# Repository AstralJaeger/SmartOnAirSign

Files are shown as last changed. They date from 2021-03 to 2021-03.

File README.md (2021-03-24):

# Smart OnAir Sign
<br />This work is licensed under a <a rel="license" href="http://creativecommons.org/licenses/by-nc-sa/4.0/">Creative Commons Attribution-NonCommercial-ShareAlike 4.0 International License</a>.

Also available on Thingiverse: https://www.thingiverse.com/thing:4804813

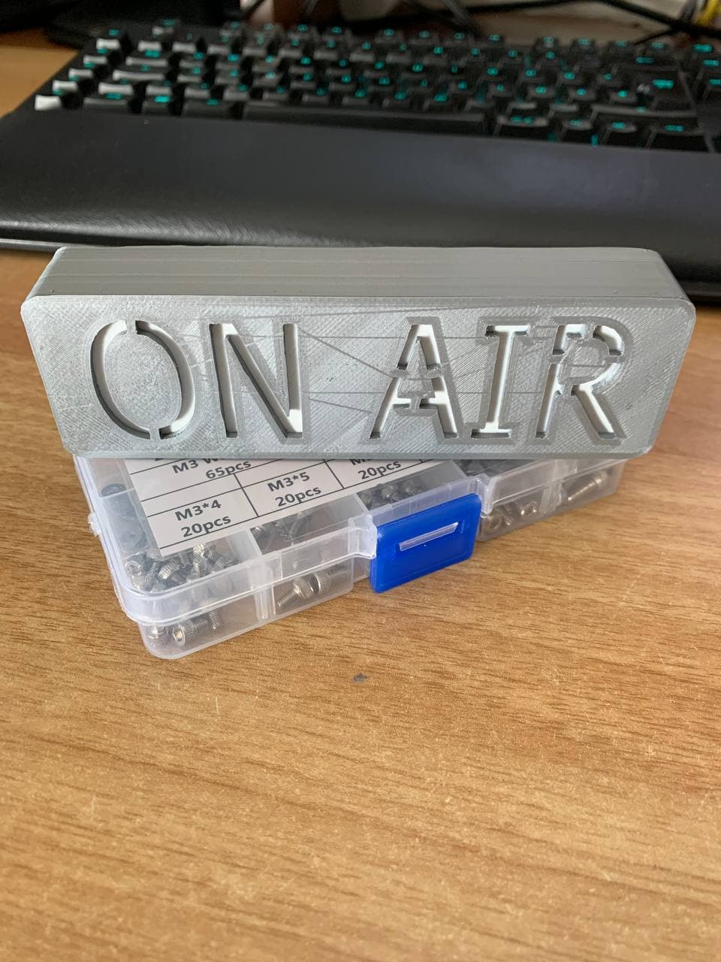
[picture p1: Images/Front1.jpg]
Front Picture

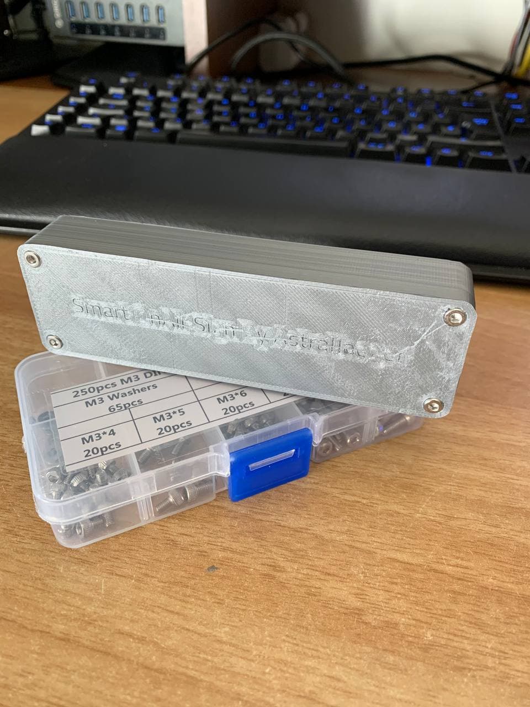
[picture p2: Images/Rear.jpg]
Rear Picture


Do you know this issue, you are in a remote meeting and suddenly your roommate/significant other walks in and wants to talk to you?
I certainly do, that's why I designed this WiFi enabled on-air sign because I couldn't find one I liked.

The device operates rather simply: 
A web server runs on a Wemos D1 mini which hosts an mDNS enabled web server with can be easily reached with the URL http://onairsign.local/. 
In order to manipulate the color the device displays the URL http://onairsign.local/color can be used with the following parameters:

| Parameter | Description | Example |
|---|---|---|
| **r** | This parameter changes the red part of the displayed color. Values range from 0 to 255, whole numbers only. | http://onairsign.local/color?r=128 |
| **g** | This parameter changes the green part of the displayed color. Values range from 0 to 255, whole numbers only. | http://onairsign.local/color?g=128 |
| **b** | This parameter changes the blue part of the displayed color. Values range from 0 to 255, whole numbers only. | http://onairsign.local/color?b=128 |
| **lum** | This parameter changes the brightness of the led's. Values range from 0 to 255, whole numbers only. | http://onairsign.local/color?lum=128 |
| **s** | This is the status parameter. Values may be 0, 1 or 2. 0 displays a rainbow wave, 1 displays the set color, 2 turns the display off.  | http://onairsign.local/color?s=1 |

## Examples
- This sets the color to red at full brightness: 
http://onairsign.local/color?r=255&g=0&b=0&lum=255&s=1
- This disables the display: http://onairsign.local/color?s=2
- This shows a rainbow wave: http://onairsign.local/color?s=0

## Required tools
- 3D printer (obviously)
- Soldering iron
- Solder 
- Allen key

## BOM
- *1 x* **[LOLIN (WEMOS) D1 Mini](https://it.aliexpress.com/item/32529101036.html?spm=a2g0s.9042311.0.0.653f4c4dwwleCD)**
- *1 x* **[WS2812B 5V LED strip](https://it.aliexpress.com/item/2036819167.html?spm=a2g0s.9042311.0.0.653f4c4dAy9aew)**
- *4-6 x* **[M3x8 or M3x12 Screws](https://it.aliexpress.com/item/32846918173.html?spm=a2g0s.9042311.0.0.653f4c4dAy9aew)**
- *1 x* **3D printed top shell**
- *1 x* **3D printed bottom shell**
- *1 x* **3D printed light diffuser or sheet of paper** (optional)

## Printing instructions
### Top shell
Avoid using a brim, turn the flat side with the text to the bottom. Do NOT drill out the screw holes, the screws should tap into this side.

### Diffuser
Print using 0.16 mm layer height, this way it will end up being 2 layers, print it in white filament. If you don't have white filament at hand, just cut out a sheet of paper or omit the whole thing, it just prevents you from seeing the electronics.

### Bottom shell
No brim should be necessary, if used, you'll have to clear out the screw holes. May need to drill out the screw holes, these are just through-holes on this side.

## Assembly
### Step 1
Glue the diffuser in place, I used some Bostik superglue, but any glue that sticks to your material of choice will do. 
The diffuser may need some trimming in the corner.

### Step 2
Cut the LED strip into 3 or 4 pieces, connect them with some short wires (1 - 1.5cm or about 1/2"). 
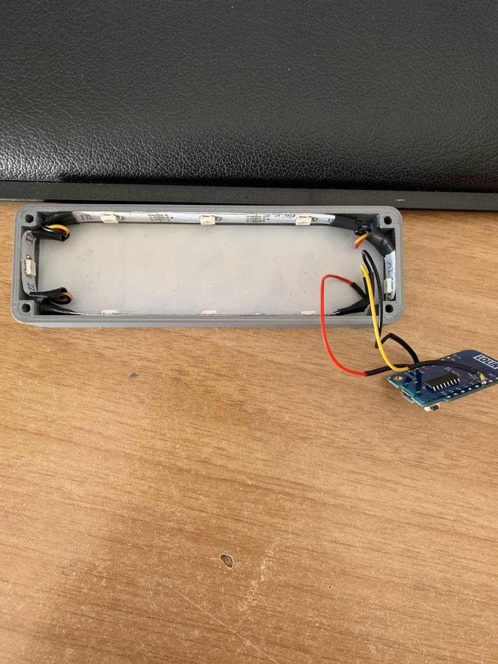
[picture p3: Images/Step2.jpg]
Step 2 - image


### Step 3
Solder a slightly longer piece of wire to the beginning of your LED strip and to the bottom (The top is the side with the USB port) of your Wemos, 5V goes to 5V, GND to GND and DIn to GPIO16 or D0 of the board.
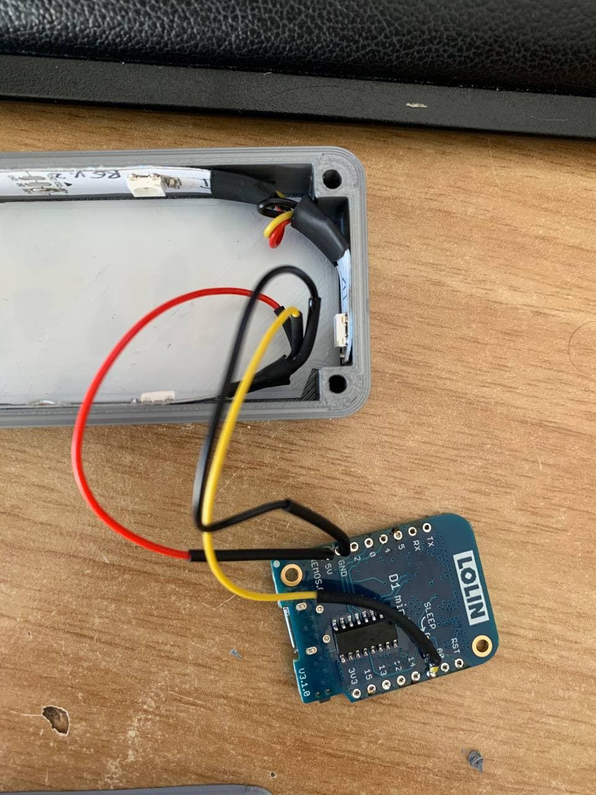
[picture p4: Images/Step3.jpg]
Step 3 - image

Step 3 - Wemos pinout

### Step 4
Push the Wemos into its slot on the bottom shell, usb port should point down, it should be a tight fit and stay in-place without any glue. 
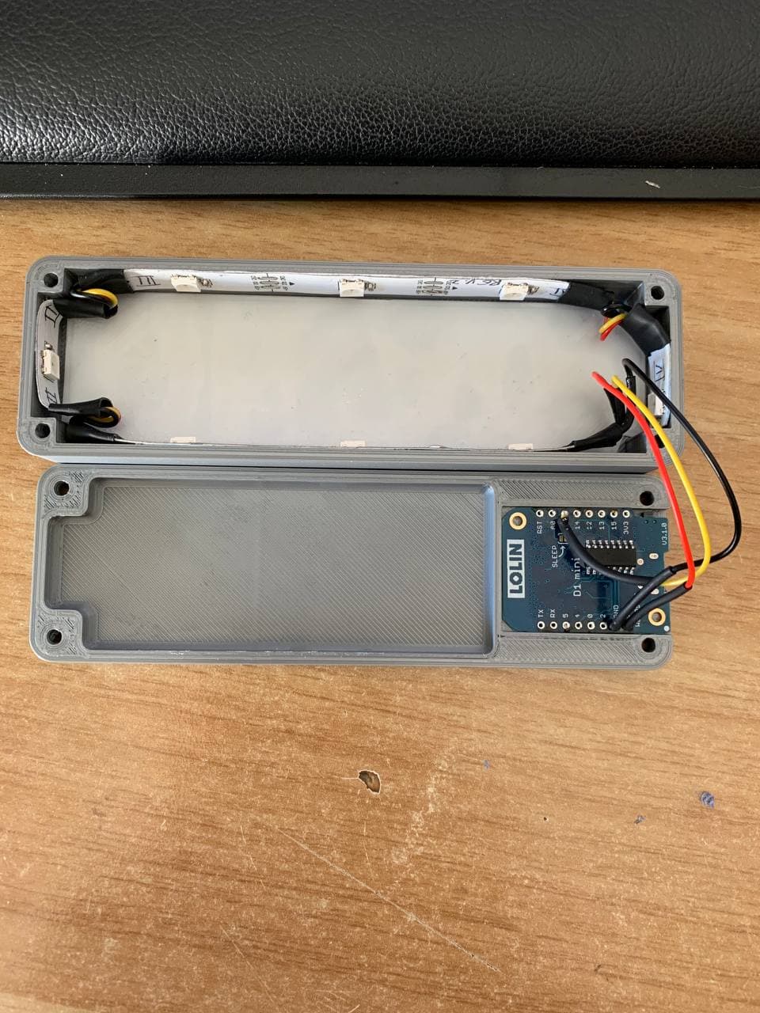
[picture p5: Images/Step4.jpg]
Step 4 - image


### Step 5
Before closing your Project, make sure to upload the code available [here](/blob/master/Code/ESP/ESP8622_Code) using the Arduino IDE or PlatformIO or VisualMicro. **Make sure to enter your WiFi ssid and password in the code!** 
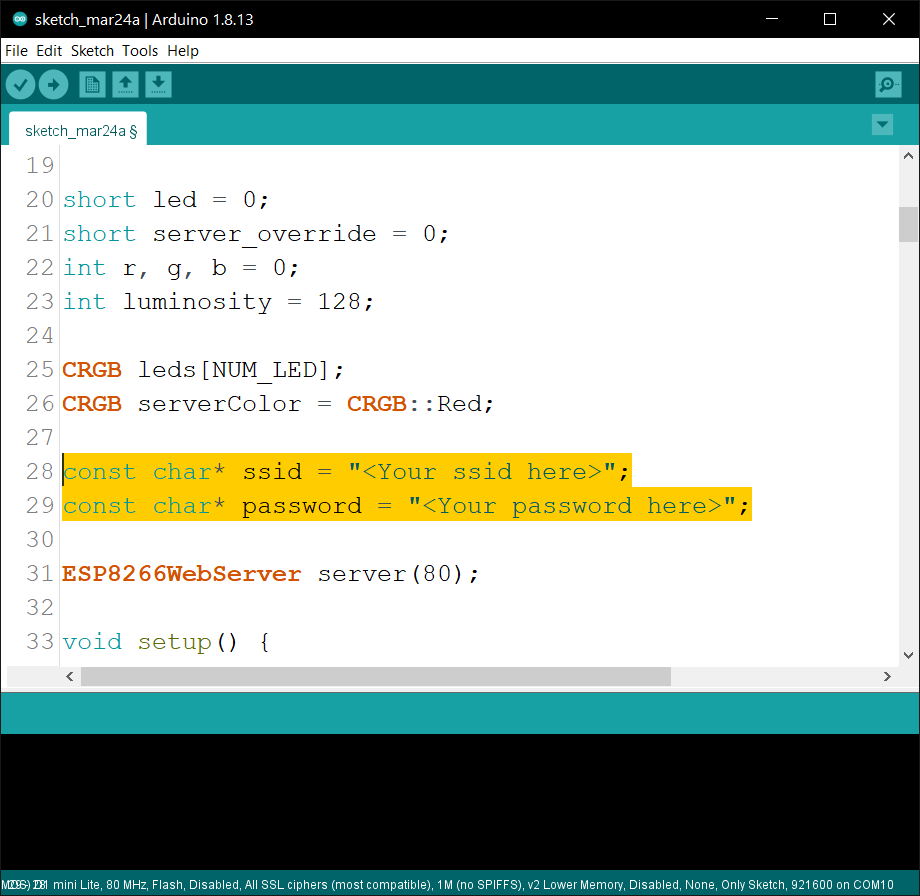
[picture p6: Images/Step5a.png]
Step 5 - Boardmanager


In order to get the correct device to upload your code you may need to add this ``https://arduino.esp8266.com/stable/package_esp8266com_index.json`` to your Preferences -> Additional Boardmanager URL's.
Then download the necessary files using the board manager.
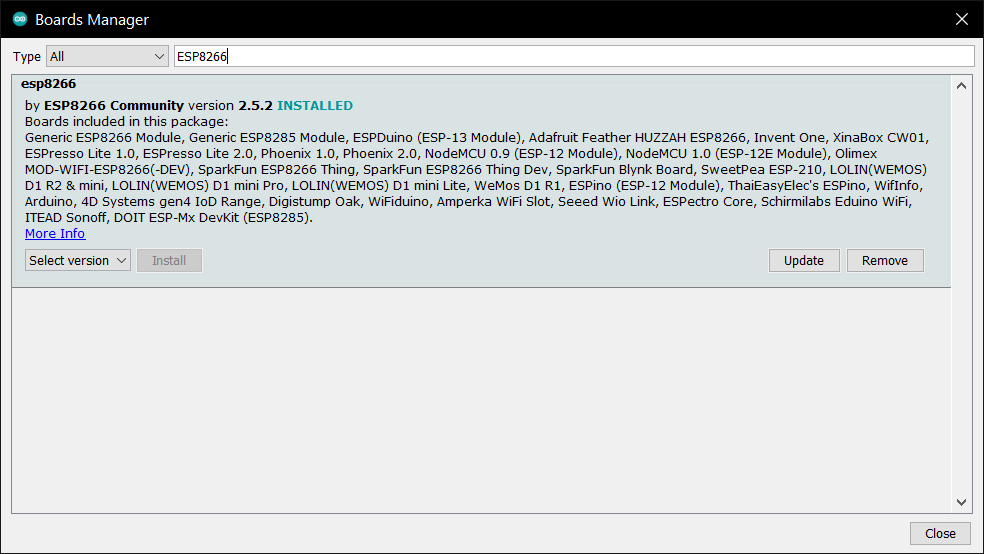
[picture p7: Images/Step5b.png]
Step 5 - Boardmanager


After uploading, open the Serial Monitor and wait for the device to start up. There is a 2 second startup sanity delay as recommended by the FastLED library.
Wait until your serial monitor output looks similar to this: 
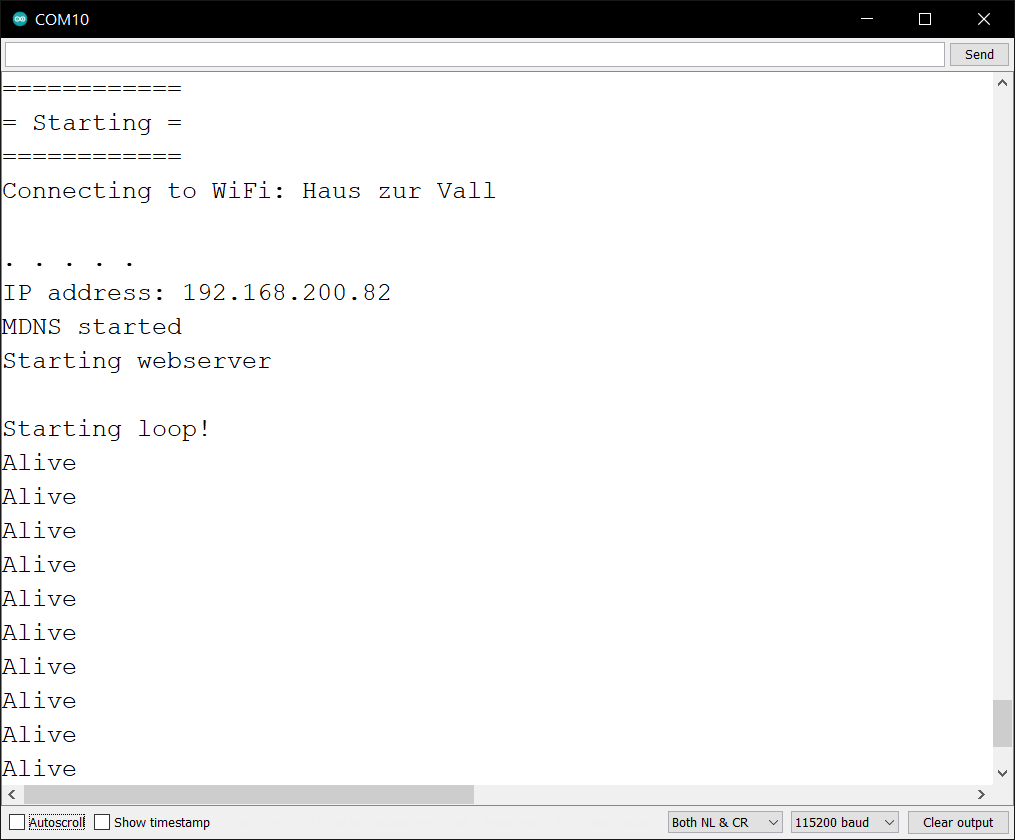
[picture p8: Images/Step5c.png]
Step 5 - Serial monitor


### Step 6
Now when your LED's light up, you can close the case and enjoy your new On Air sign!
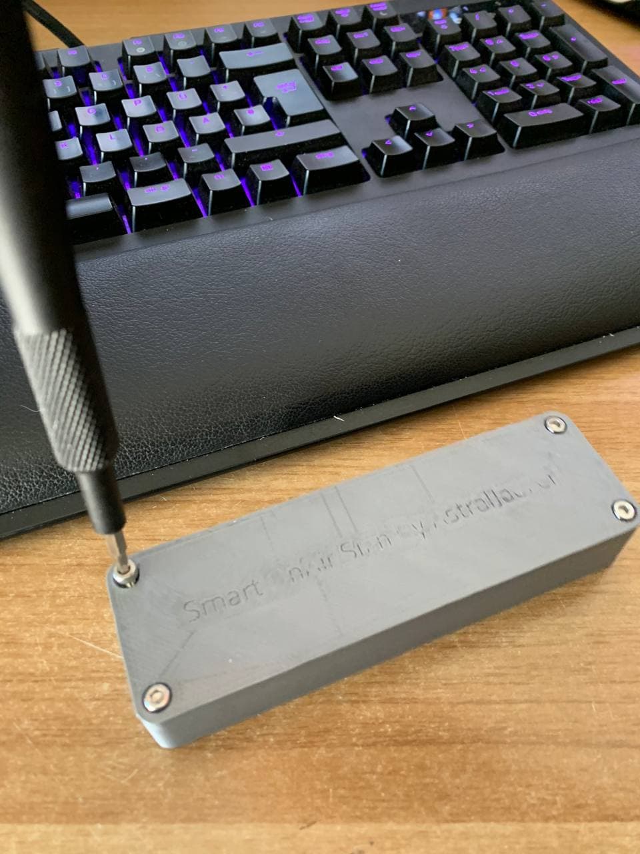
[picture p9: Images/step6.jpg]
Step 6 - Last screw


## BOM Reference Pictures
- LOLIN D1 Mini
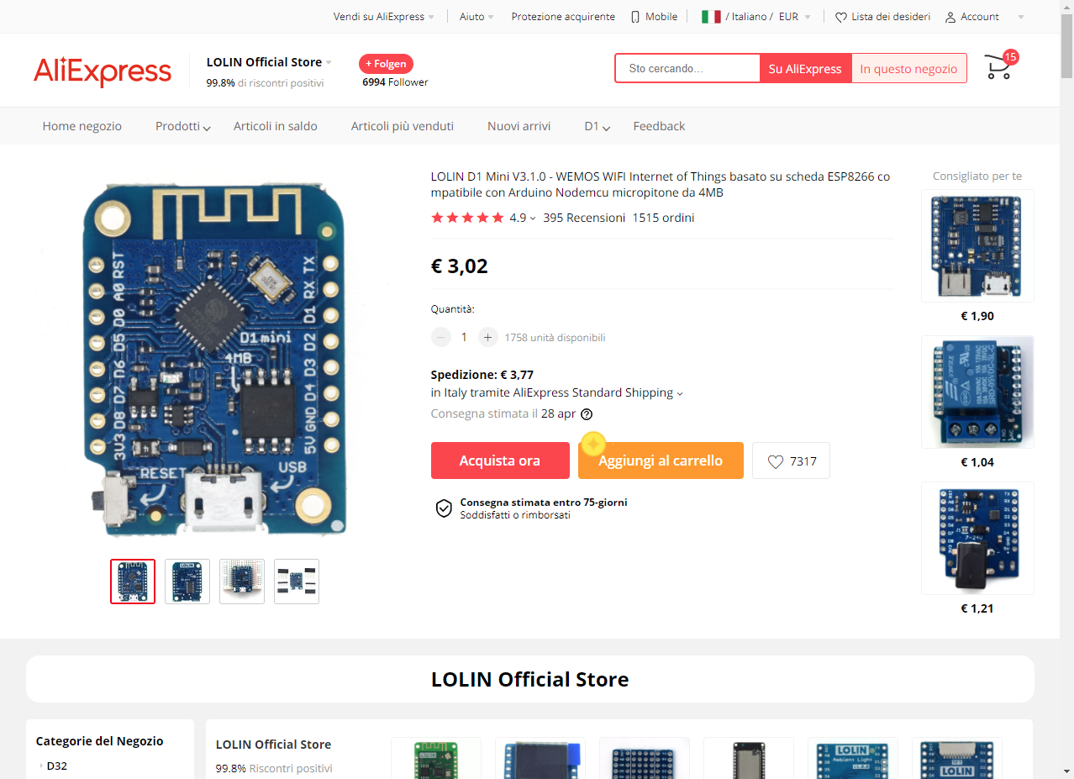
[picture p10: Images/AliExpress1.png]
Wemos D1 mini

- ARGB LED Strip
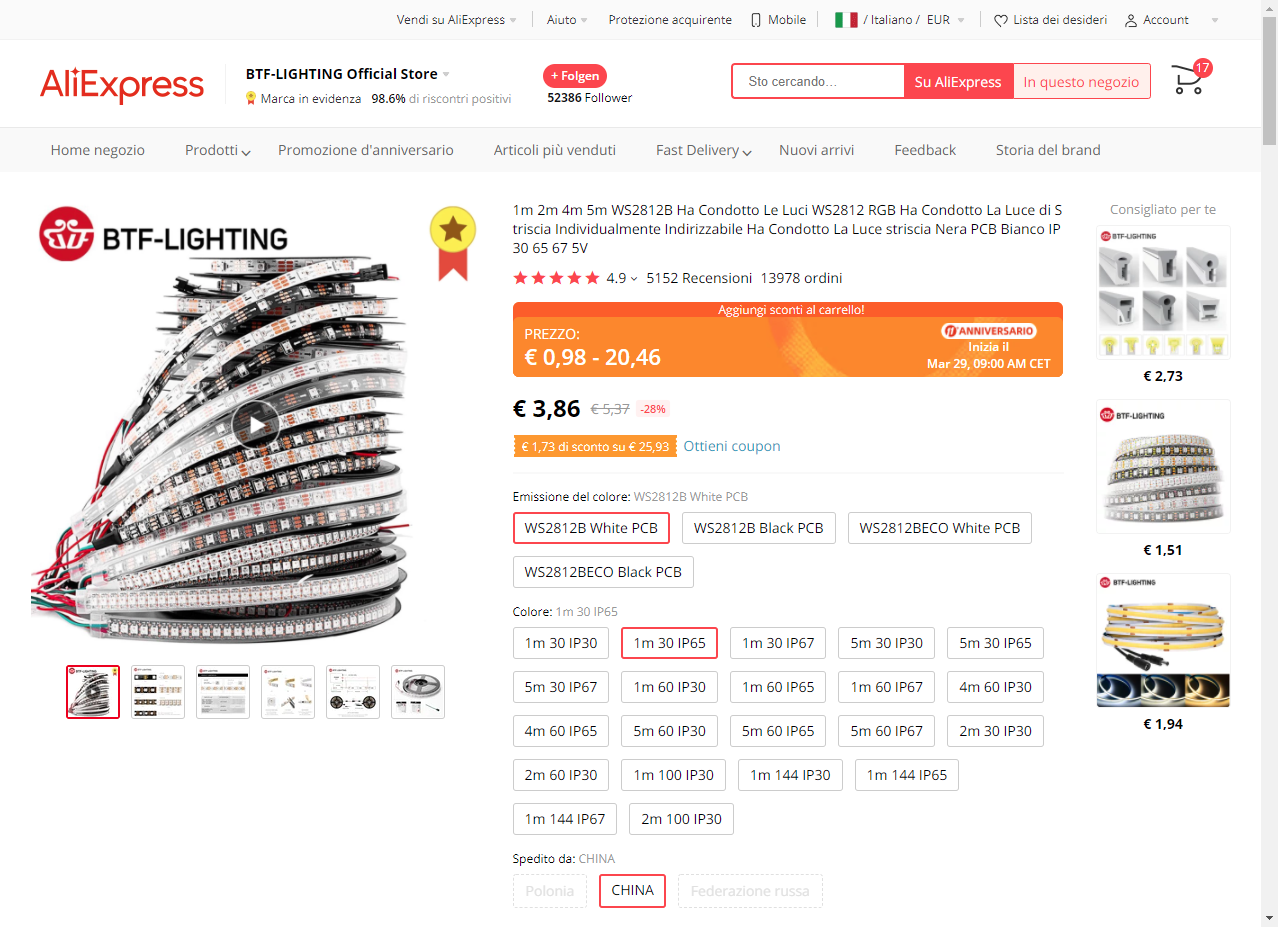
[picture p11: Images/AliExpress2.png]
ARGB LED strip

- M3 Screws
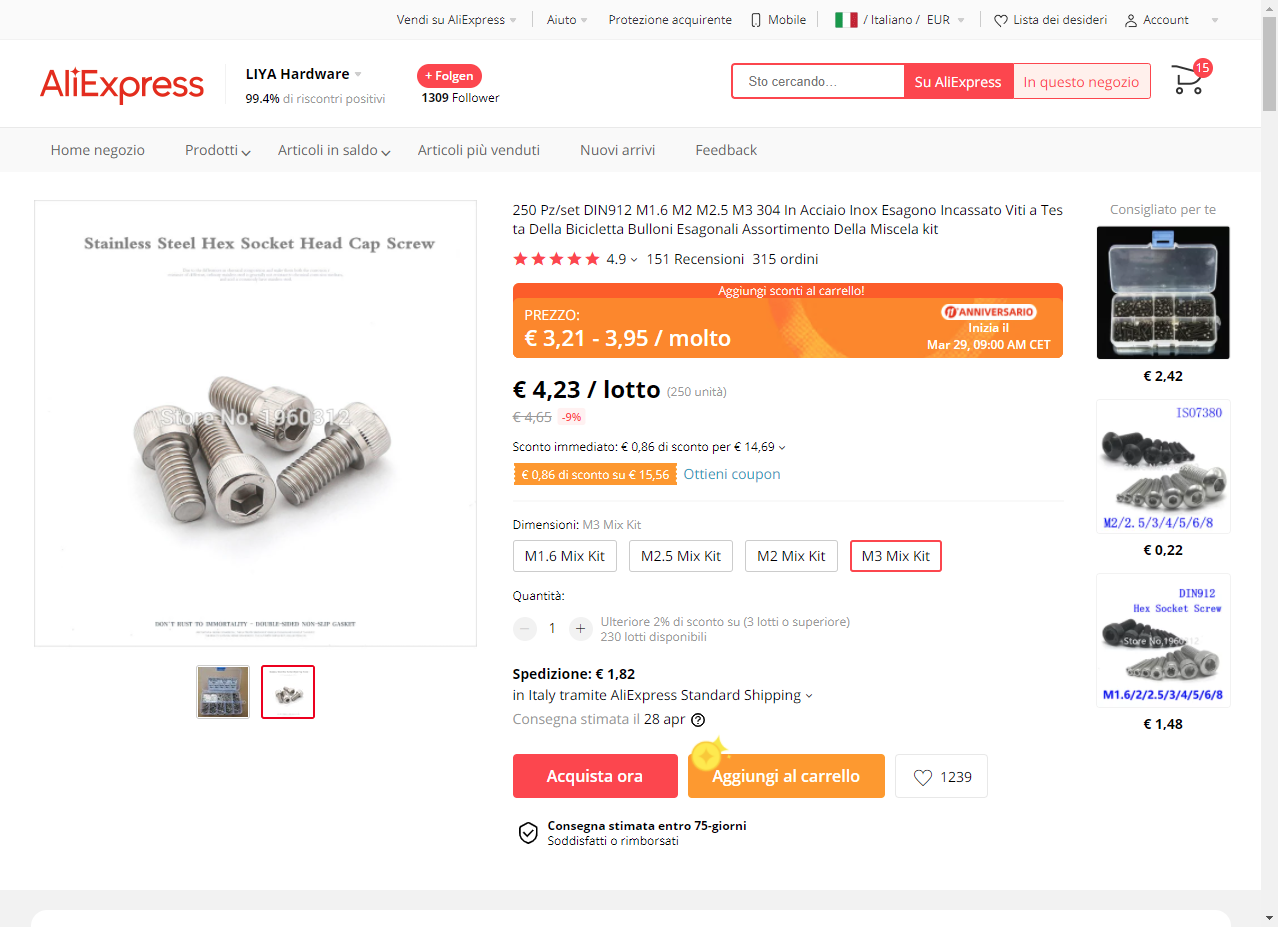
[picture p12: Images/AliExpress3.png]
M3 Screws


## Planned updates
- Python program to monitor Discord, Zoom and Twitch for activity and enable the sign automatically
- Bottom shell with various mounting options
- RaspberryPi Zero instead of ESP

## Updates
24.03.2021 - Create first version

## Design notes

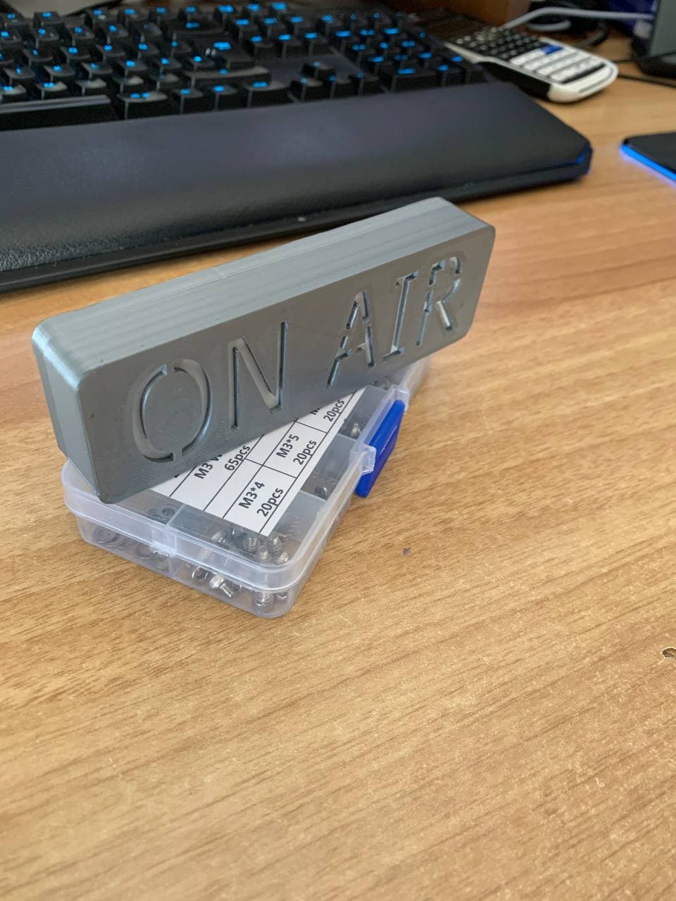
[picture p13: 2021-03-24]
Images/Front.jpg

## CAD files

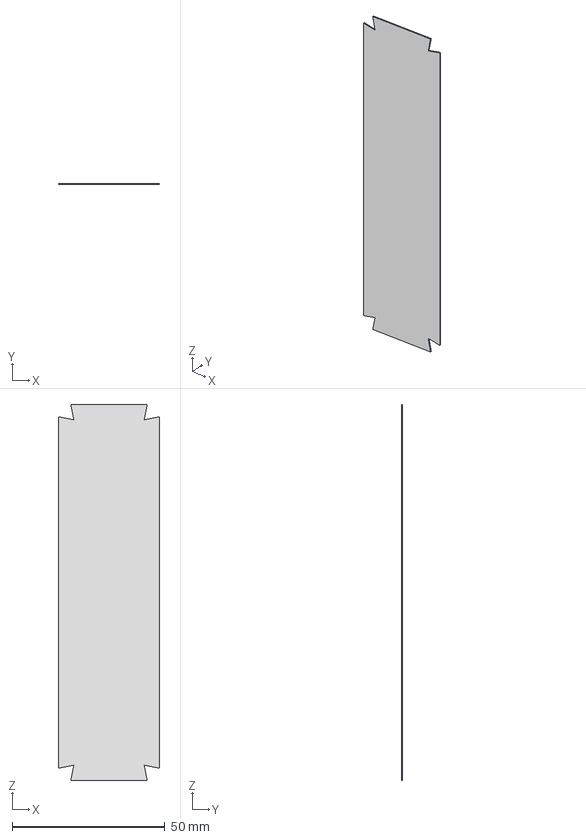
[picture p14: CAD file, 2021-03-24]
3dfiles/Diffuser.stp
33.0 x 0.41 x 123.0 mm

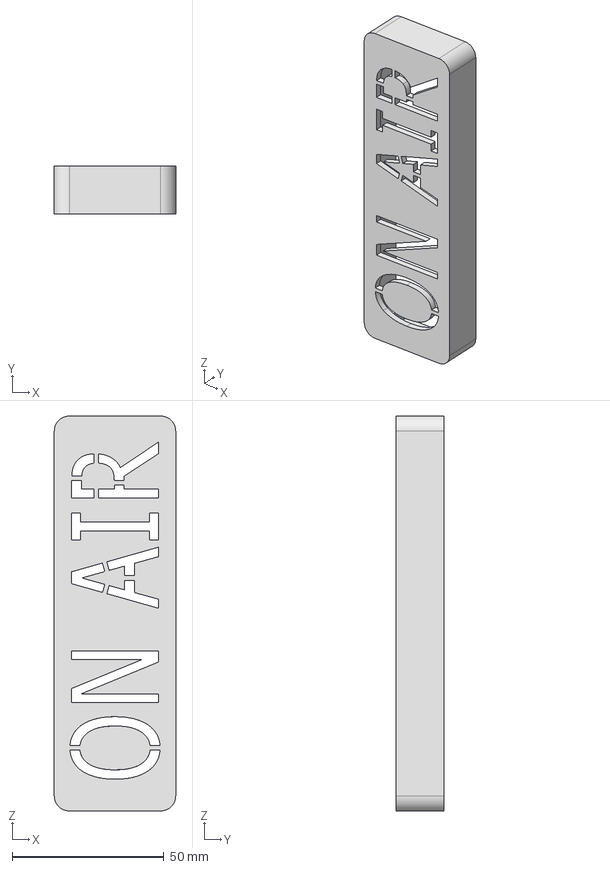
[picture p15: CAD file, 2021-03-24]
3dfiles/Top Shell.stp
40.0 x 15.8 x 130.0 mm

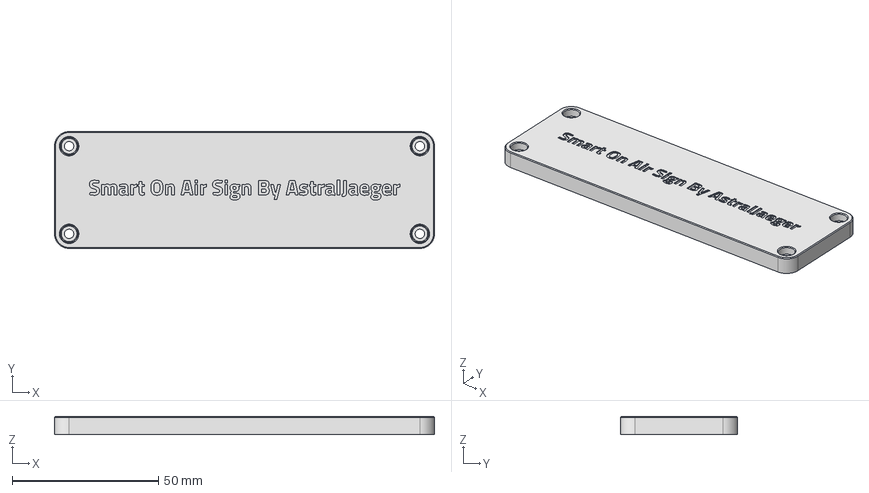
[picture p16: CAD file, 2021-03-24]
3dfiles/Bottom Shell.stp
130.0 x 40.0 x 6.25 mm

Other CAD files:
3dfiles/Bottom Shell.stl
3dfiles/Diffuser.stl
3dfiles/Top Shell.stl

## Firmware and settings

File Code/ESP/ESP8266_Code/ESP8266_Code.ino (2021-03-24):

/*
 * This program was written by Felix Hillebrand 2021
 * This program is published under the Creative Commons Attribution-NonCommercial-ShareAlike 4.0 International license
 */

#include <ESP8266WiFi.h>
#include <WiFiClient.h>
#include <ESP8266WebServer.h>
#include <ESP8266mDNS.h>
#include <FastLED.h>

#define MDNS_NAME "onairsign"

#define NUM_LED   8
#define DATA_PIN 16
#define LED_PIN   2

#define STARTUP_DELAY 2000l
#define WIFI_TIMEOUT 10000l

long pre_millis = 0;
long cur_millis = 0;
long intv = 1000;

short led = 0;
short server_override = 0;
int r, g, b = 0;
int luminosity = 128;

CRGB leds[NUM_LED];
CRGB serverColor = CRGB::Red;

const char* ssid = "<Your ssid here>";
const char* password = "<Your password here>";

ESP8266WebServer server(80);

void setup() {
    delay(STARTUP_DELAY);

    Serial.begin(115200);
    Serial.println("\n============"); 
    Serial.println("= Starting =");
    Serial.println("============");

    FastLED.addLeds<WS2812B, DATA_PIN, GRB>(leds, NUM_LED);
    FastLED.setBrightness(luminosity);
    FastLED.setMaxPowerInVoltsAndMilliamps(5, 1000);
    
    initWiFi();
    initmDNS();
    initWebServer();

    pinMode(LED_PIN, OUTPUT);
    Serial.println("\nStarting loop!");
    setColor(CRGB::AliceBlue);
    FastLED.show();
    delay(STARTUP_DELAY);
}

void initWiFi() {
    Serial.print("Connecting to WiFi: ");
    Serial.println(ssid);
    WiFi.mode(WIFI_STA);
    WiFi.begin(ssid, password);
    Serial.println("");
    long start = millis();
    long current = 0;
    while (WiFi.status() != WL_CONNECTED) {
        Serial.print(". ");
        delay(500);
        current = millis();
        if (led == 0) {
            led = 1;
            if (current - start >= WIFI_TIMEOUT) {
                setColor(CRGB::FireBrick);
            }
            else {
                setColor(CRGB::Amethyst);
            }
        }
        else {
            led = 0;
            setColor(CRGB::Black);
        }
    }
    Serial.println("");
    Serial.print("IP address: ");
    Serial.println(WiFi.localIP());
}

void initmDNS() {
    if (!MDNS.begin(MDNS_NAME)) {
        Serial.println("Error setting up MDNS responder!");
        while (1) {
            delay(1000);
            if (led == 0) {
                led = 1;
                setColor(CRGB::Red);
            }
            else {
                led = 0; 
                setColor(CRGB::Black);
            }
            FastLED.show();
        }
    }
    MDNS.addService("http", "tcp", 80);
    Serial.println("MDNS started");
}

void initWebServer() {
    Serial.println("Starting webserver");

    // Setup routing
    server.on("/", HTTP_GET, []() {
        server.send(200, F("text/html"),
            F("Welcome to the REST Web Server"));
    });
    server.on("/color", HTTP_POST, handleColor); 
    server.on("/color", HTTP_GET, handleColor);

    // Setup NotFound
    server.onNotFound(handleNotFound);

    // Start server
    server.begin();
}

void handleNotFound() {
    String msg = "FILE NOT FOUND\n\nURI: ";
    msg += server.uri();
    msg += "\nMethod: ";
    msg += (server.method() == HTTP_GET) ? "GET" : "POST";
    msg += "\nArguments: ";
    msg += server.args();
    msg += "\n";
    for (uint8_t i = 0; i < server.args(); i++) {
        msg += " " + server.argName(i) + ": " + server.arg(i) + "\n";
    }
    
    msg += "Headers: ";
    msg += server.headers();
    msg += "\n";
    for (uint8_t i = 0; i < server.headers(); i++) {
        msg += " " + server.headerName(i) + ": " + server.header(i) + "\n";
    }
   
    server.send(404, "text/plain", msg);
}

void handleColor() {
    for (uint8_t i = 0; i < server.args(); i++) {
        if (server.argName(i).equalsIgnoreCase("r")) {
            r = server.arg(i).toInt();
        }
        else if(server.argName(i).equalsIgnoreCase("g")) {
            g = server.arg(i).toInt();
        }
        else if (server.argName(i).equalsIgnoreCase("b")) {
            b = server.arg(i).toInt();
        }
        else if (server.argName(i).equalsIgnoreCase("lum")) {
            luminosity = server.arg(i).toInt();
        }
        else if (server.argName(i).equalsIgnoreCase("s")) {
            server_override = server.arg(i).toInt();
        }
    }

    server.send(200, "none", "");
}

void loop() {
    MDNS.update();
    server.handleClient();

    if (server_override == 0) {
        rainbow_wave(25, 2);
    }
    else if(server_override == 1){
        setColor(CRGB(r, g, b));
        FastLED.setBrightness(luminosity);
    } else {
        setColor(CRGB::Black);
    }

    cur_millis = millis();
    if (cur_millis - pre_millis >= intv) {
        Serial.println("Alive");
        if (led == 1) {
            digitalWrite(LED_PIN, HIGH);
            led = 0;
        }
        else {
            digitalWrite(LED_PIN, LOW);
            led = 1;
        }
        pre_millis = cur_millis;
    }

    FastLED.show();
}

void rainbow_wave(uint8_t speed, uint8_t delta) {
    uint8_t hue = beat8(speed, 255);
    fill_rainbow(leds, NUM_LED, hue, delta);
}

void setColor(CRGB color) {
    for (int i = 0; i < NUM_LED; i++) {
        leds[i] = color;
    }
}

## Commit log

2021-03-24 Add images and assembly instructions
2021-03-24 Add 3D files
    [Bottom Shell.stl, Bottom Shell.stp, Diffuser.stl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]
